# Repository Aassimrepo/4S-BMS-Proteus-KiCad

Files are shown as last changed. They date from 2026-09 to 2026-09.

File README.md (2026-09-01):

# 4S Battery Management System (BMS)

### Proteus Simulation & KiCad PCB Design

A simulation-based **4S Battery Management System (BMS)** designed to monitor individual battery cells, estimate pack state, detect abnormal operating conditions, and control passive cell balancing.

The project combines **Arduino-based embedded control, Proteus circuit simulation, and KiCad PCB design** to develop and validate the BMS architecture before physical hardware fabrication.

---

## Overview

A Battery Management System is responsible for monitoring and protecting rechargeable battery packs during charging and discharging.

This project implements a **4-series-cell (4S) BMS**, where each individual cell is monitored independently. The system measures cell voltage, pack voltage, current, and temperature while providing protection and balancing functionality.

The complete design was developed and tested in simulation using **Proteus**, while the corresponding PCB was designed and routed using **KiCad**.

> **Note:** This is a simulation and PCB-design project. No physical battery hardware is used in the current implementation.

---

## Key Features

* Individual voltage monitoring for all **4 battery cells**
* Total battery pack voltage calculation
* Battery **State of Charge (SOC)** estimation
* Overvoltage protection
* Undervoltage protection
* Overcurrent detection
* Overtemperature detection
* Passive cell-balancing control
* Individual cell-balancing indicators
* Charge and load status indication
* Fault indication
* ACS712-based current sensing model
* NTC thermistor temperature sensing
* Nokia 5110 LCD monitoring
* Arduino-based embedded control
* Serial telemetry between controllers
* Complete KiCad schematic and PCB layout
* PCB routing and Design Rules Check (**DRC**)

---

## System Architecture

```text
                     ┌──────────────────────┐
                     │      4S Battery      │
                     │   Cell 1 - Cell 4   │
                     └──────────┬───────────┘
                                │
                                ▼
                     ┌──────────────────────┐
                     │   Voltage Divider    │
                     │   Sensing Network    │
                     └──────────┬───────────┘
                                │
                                ▼
                 ┌──────────────────────────────┐
                 │      Arduino BMS Controller  │
                 │                              │
                 │ • Cell Voltage Monitoring    │
                 │ • Pack Voltage Calculation   │
                 │ • SOC Estimation             │
                 │ • Fault Detection            │
                 │ • Balancing Control          │
                 └───────┬──────────┬───────────┘
                         │          │
              ┌──────────┘          └───────────┐
              ▼                                 ▼
      ┌───────────────┐                 ┌───────────────┐
      │  Nokia 5110   │                 │ Status / Fault│
      │     LCD       │                 │     LEDs      │
      └───────────────┘                 └───────────────┘
                         │
                         ▼
                 ┌─────────────────┐
                 │ Secondary MCU / │
                 │ Telemetry Link  │
                 └─────────────────┘
```

---

## Cell Voltage Measurement

The four battery-cell inputs are measured using resistor-divider networks connected to the Arduino's analog inputs.

The divider networks allow the cumulative battery tap voltages to be scaled into a measurable ADC range.

| Cell | Divider Network | Software Scaling |
| --- | --- | ---: |
| Cell 1 | 10k / 10k | ×2 |
| Cell 2 | 20k / 10k | ×3 |
| Cell 3 | 30k / 10k | ×4 |
| Cell 4 | 40k / 10k | ×5 |

The controller converts the measured ADC values into cell-voltage estimates and calculates the pack voltage from the four cell measurements.

---

## Battery Monitoring

The system continuously monitors:

* Cell 1 voltage
* Cell 2 voltage
* Cell 3 voltage
* Cell 4 voltage
* Pack voltage
* State of Charge (SOC)
* Battery current
* Battery temperature

ADC averaging and software filtering are used to reduce measurement fluctuations and reject invalid readings during simulation.

---

## Protection System

The BMS evaluates the measured parameters against configurable safety thresholds.

### Overvoltage

Each cell voltage is independently checked against the configured overvoltage threshold.

### Undervoltage

Each cell is monitored for voltage falling below the configured undervoltage threshold.

### Overcurrent

The ACS712 sensor model provides the current measurement. The calculated current is compared with the configured current limit.

### Overtemperature

An NTC thermistor model is used to estimate battery temperature. The system generates an overtemperature condition when the configured temperature threshold is exceeded.

### Fault Indication

When a protection condition is detected, the BMS updates its fault state and controls the corresponding protection/status outputs.

---

## Passive Cell Balancing

The BMS implements simulated passive balancing for each individual cell.

```text
Cell 1 ──► BAL1
Cell 2 ──► BAL2
Cell 3 ──► BAL3
Cell 4 ──► BAL4
```

Each balancing channel can be activated independently depending on the measured cell voltage.

The balancing state is also encoded into a telemetry value for communication to the secondary controller.

---

## LCD Interface

A **Nokia 5110 LCD** provides local monitoring of the simulated battery system.

The display provides multiple monitoring pages containing:

### Cell Monitoring

* Cell 1 voltage
* Cell 2 voltage
* Cell 3 voltage
* Cell 4 voltage
* Pack voltage
* SOC

### Current & Temperature

* Battery current
* Battery temperature

### Pack Summary

* Pack voltage
* SOC
* Telemetry status

---

## Controller Communication

The primary controller periodically transmits monitoring information to the secondary controller through serial communication.

The telemetry packet contains:

```text
Cell 1
Cell 2
Cell 3
Cell 4
Pack Voltage
SOC
Current
Temperature
Fault Code
Balancing Code
```

### Fault Codes

| Code | Condition |
| ---: | --- |
| 0 | No Fault |
| 1 | Overvoltage |
| 2 | Undervoltage |
| 3 | Overcurrent |
| 4 | Overtemperature |

The balancing status is represented using a bit-coded value, allowing the state of the four balancing channels to be transmitted efficiently.

---

## Proteus Simulation

The complete BMS control system is simulated in **Proteus**.

The simulation models:

* Battery-cell voltage inputs
* Voltage-divider sensing circuits
* Arduino controllers
* ACS712 current sensor
* NTC thermistor
* Nokia 5110 LCD
* Status LEDs
* Cell-balancing outputs
* Serial communication

Different operating conditions can be introduced by changing the simulated sensor and battery inputs.

This allows the BMS control logic to be evaluated without physical battery hardware.

---

## PCB Design

The corresponding BMS PCB was designed using **KiCad**.

The PCB design includes the circuitry required for:

* Battery connections
* Cell-voltage sensing
* Current sensing
* Temperature sensing
* Microcontroller interfaces
* Cell balancing
* Status indicators
* Buzzer
* Display interface
* Communication interfaces
* ESP8266 interface

The PCB was routed and subsequently checked using KiCad's Design Rules Checker.

---

## PCB Validation

The completed PCB layout was subjected to KiCad's **Design Rules Check (DRC)**.

### Final DRC Result

```text
0 Violations
```

This confirms that the final PCB layout passed the configured KiCad design-rule checks.

---

## Repository Structure

```text
4S-BMS-Proteus-KiCad/
│
├── Proteus/
│   ├── Simulation/
│   │   ├── *.dsn
│   │   └── *.pdsprj
│   │
│   ├── Arduino_Code/
│   │   ├── *.ino
│   │   └── ...
│   │
│   └── HEX_Files/
│       └── *.hex
│
├── KiCad_PCB/
│   ├── Source/
│   │   ├── *.kicad_pro
│   │   ├── *.kicad_sch
│   │   └── *.kicad_pcb
│   │
│   └── Outputs/
│       ├── PCB_3D_Render.png
│       └── PCB_Layout.png
│
├── Documentation/
│   ├── Screenshots/
│   └── Results/
│
├── .gitignore
└── README.md
```

---

## Testing

The simulated BMS can be evaluated under different operating conditions.

| Test Condition | Input | Expected Behaviour |
| --- | --- | --- |
| Normal Operation | Normal cell voltages | Normal monitoring |
| Overvoltage | Cell exceeds OV limit | Fault/protection indication |
| Undervoltage | Cell falls below UV limit | Load protection/fault |
| Overcurrent | Current exceeds limit | Overcurrent protection |
| Overtemperature  | Temperature exceeds limit | Temperature protection |
| Cell Balancing | Cell reaches balancing threshold | Corresponding balancing output |
| Recovery | Fault condition removed | Return to normal operation |

Screenshots demonstrating the simulation and PCB validation are available in the `Documentation/Screenshots` directory.

---

## Technologies Used

### Hardware / Controllers

* Arduino Uno
* Arduino Nano
* ESP8266 interface
* ACS712 current sensor
* NTC thermistor
* Nokia 5110 LCD
* Passive balancing circuitry

### Software

* Proteus
* KiCad
* Arduino IDE
* C/C++

---

## Future Development

The project can be extended into an IoT-enabled battery monitoring platform.

Planned extensions include:

* Raspberry Pi 5 IoT gateway
* Real-time web dashboard
* Remote BMS telemetry
* Live voltage/current/temperature graphs
* Historical data logging
* Battery-state prediction
* Machine-learning based battery analysis
* Remote fault notifications
* Physical hardware implementation and validation

These features are intended as future extensions and are **not represented as completed functionality in the current version of the repository**.

---

## Project Documentation

The repository contains screenshots showing:

* Complete Proteus simulation
* Normal BMS operation
* Fault detection
* PCB routing
* PCB 3D visualization
* KiCad DRC results

Refer to:

```text
Documentation/Screenshots/
```

for the available visual documentation.

---

## Disclaimer

This project is intended for **educational and research purposes**.

The current implementation is a simulation and PCB-design study and has not been validated on physical battery hardware.

A real battery-management system requires appropriate component selection, isolation, protection circuitry, thermal considerations, battery characterization, hardware validation, and extensive safety testing before being used with a real battery pack.

---

## Author

**Aassim Basheer**

Electronics and Communication Engineering

---

## License

This project is provided for educational and research purposes.

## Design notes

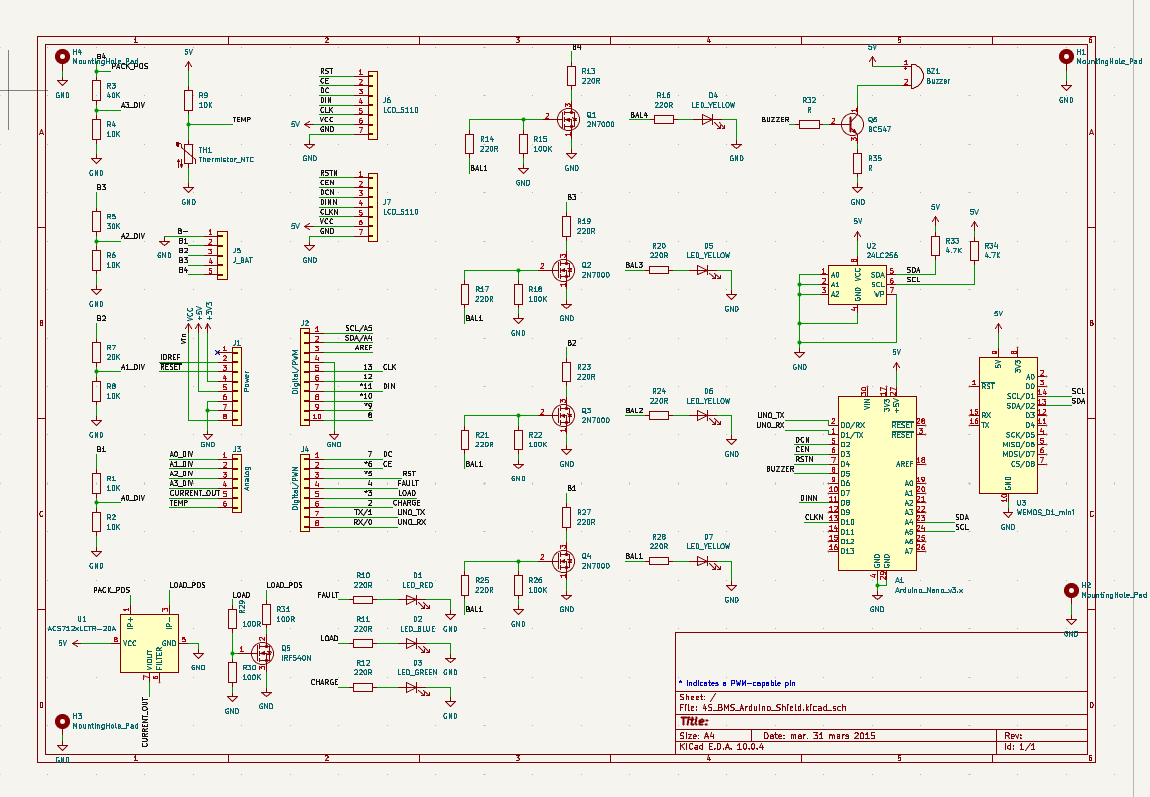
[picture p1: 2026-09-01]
Documentation/Screenshots/PCB SCHEMATIC.png

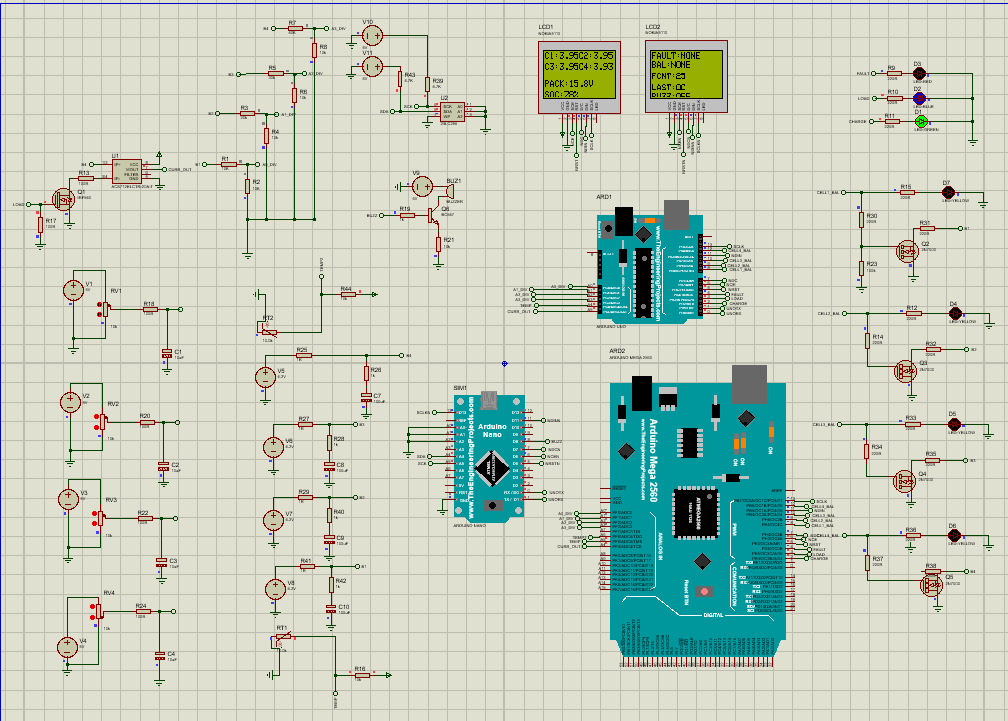
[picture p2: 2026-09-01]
Documentation/Screenshots/PROTEUS SIMULATION.png

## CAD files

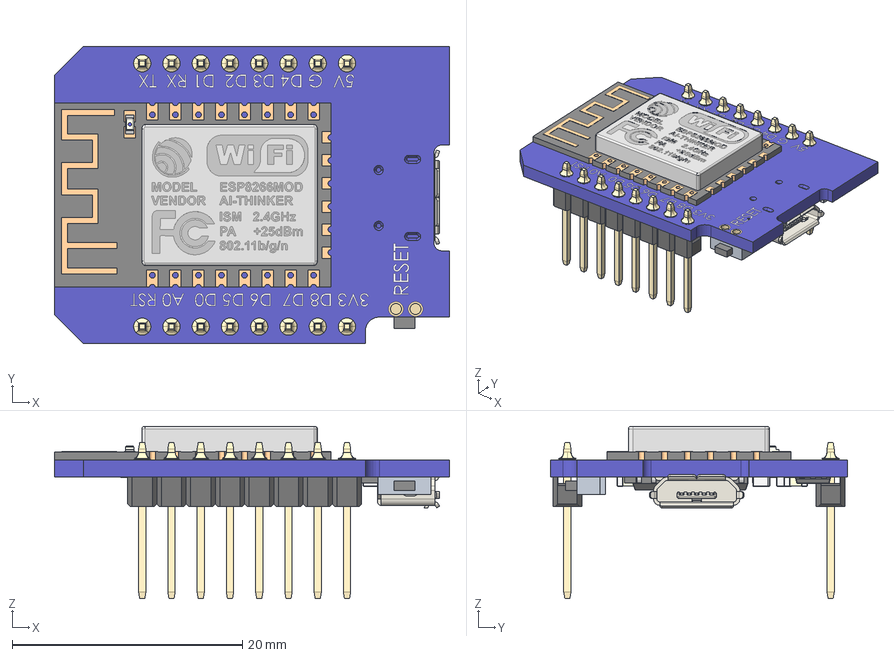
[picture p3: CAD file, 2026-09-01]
KiCad_PCB/Source/kicad bms/wemos-mini-d1.stp
34.3 x 25.8 x 14.9 mm
PRODUCT_146_ASM_2
PRODUCT_260_3
PRODUCT_323_ASM_2
RES_0805_1 x 12
CAP_0805_1 x 7
SOT23_1_1 x 2
SOT23_2_1 x 2
SOT23_3_1 x 2
SOT23_001_1 x 2
SOT23-5_1
SOT23-5_001_1_1
SOT23-5_001_2_1
SOT23-5_001_3_1
SOT23-5_001_4_1
SOT23-5_001_5_1
SOD-323_1
SOIC-16_150MIL_1
SOIC-16_150MIL_001_1_1
SOIC-16_150MIL_001_2_1
SOIC-16_150MIL_001_3_1
SOIC-16_150MIL_001_4_1
SOIC-16_150MIL_001_5_1
SOIC-16_150MIL_001_6_1
SOIC-16_150MIL_001_7_1
SOIC-16_150MIL_001_8_1
SOIC-16_150MIL_001_9_1
SOIC-16_150MIL_001_10_1
SOIC-16_150MIL_001_11_1
SOIC-16_150MIL_001_12_1
SOIC-16_150MIL_001_13_1
SOIC-16_150MIL_001_14_1
SOIC-16_150MIL_001_15_1
SOIC-16_150MIL_001_16_1
COMPONENTS_2_11__2
_PUSH_BUTTON_-_IMPORTIERT1__2
_USB_SOCKET_-_IMPORTIERT1__2
PCB_2
PIN x 16

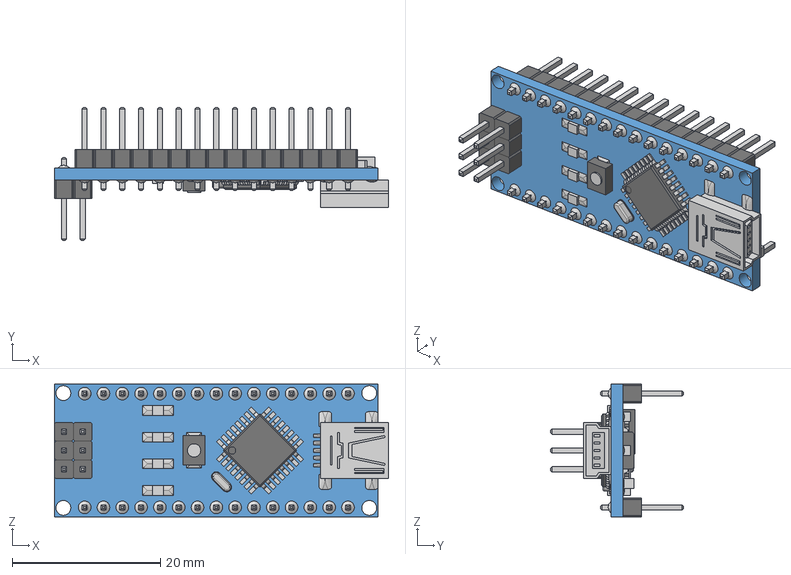
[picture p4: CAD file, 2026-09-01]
KiCad_PCB/Source/kicad bms/Arduino Nano V3.step
45.1 x 18.0 x 17.9 mm
switch
Led x 3
Led (1)
Pin x 21
chip1
USB
Crystal
Pin (1) x 15
Res x 5
cap x 2
Chip
respack x 2
diode
vreg

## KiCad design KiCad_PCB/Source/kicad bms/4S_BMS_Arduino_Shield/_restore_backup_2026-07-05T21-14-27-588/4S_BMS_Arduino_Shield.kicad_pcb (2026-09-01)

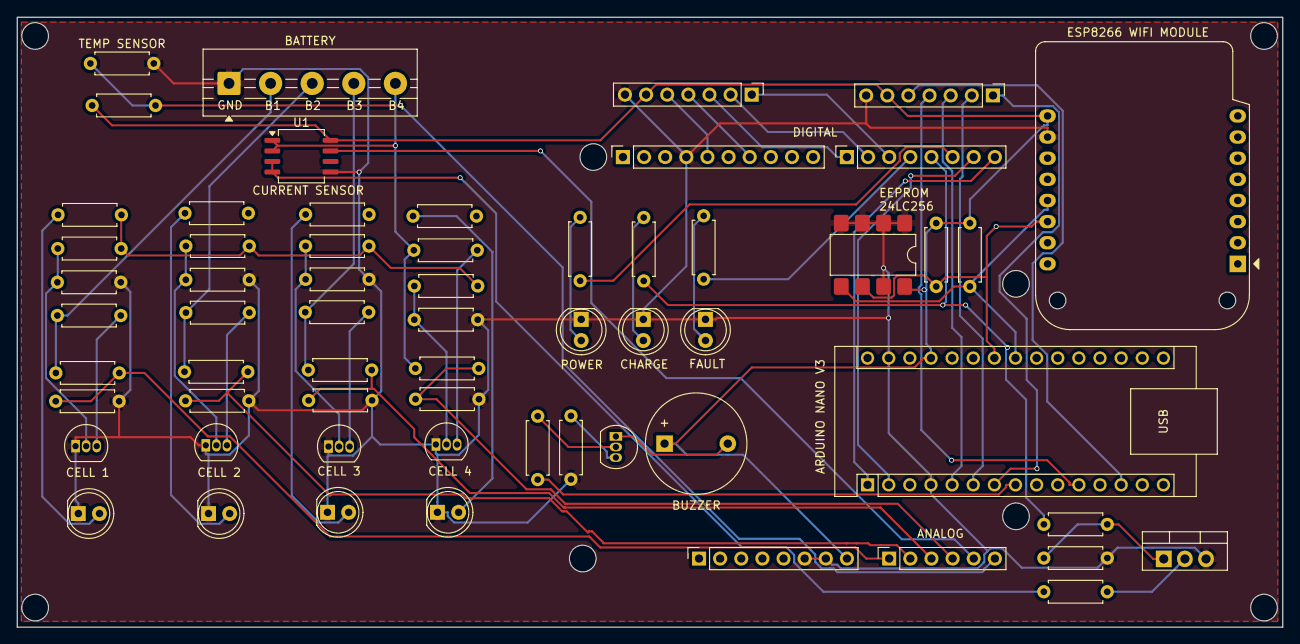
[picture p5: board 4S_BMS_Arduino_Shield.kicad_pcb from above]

Board: 2 copper layers, 152.1 x 73.3 mm, 69 parts (0 on the bottom side), 52 nets.

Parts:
A1: ARDUINO_NANO; Arduino_Nano
BATTERY: J_BAT; TerminalBlock_MaiXu_MX126-5.0-05P_1x05_P5.00mm
BZ1: BUZZER; Buzzer_12x9.5RM7.6
D1: FAULT; LED_D5.0mm
D2: CHARGE; LED_D5.0mm
D3: POWER; LED_D5.0mm
D4: BAL_4; LED_D5.0mm
D5: BAL_3; LED_D5.0mm
D6: BAL_2; LED_D5.0mm
D7: BAL_1; LED_D5.0mm
H1, H2, H3, H4: MountingHole_Pad; MountingHole_3.2mm_M3
J1: Power; PinSocket_1x08_P2.54mm_Vertical
J2: Digital/PWM; PinSocket_1x10_P2.54mm_Vertical
J3: Analog; PinSocket_1x06_P2.54mm_Vertical
J4: Digital/PWM; PinSocket_1x08_P2.54mm_Vertical
J6: LCD_1; PinHeader_1x07_P2.54mm_Vertical
J7: LCD_2; PinHeader_1x07_P2.54mm_Vertical
MH1, MH2, MH3, MH4: MountingHole_3.2mm
Q1, Q2, Q3, Q4: 2N7000; TO-92_Inline
Q5: LOAD; TO-220-3_Vertical
Q6: BC547; TO-92_Inline
R1, R2, R4, R6, R8, R9: 10K; R_Axial_DIN0207_L6.3mm_D2.5mm_P7.62mm_Horizontal
R3: 40K; R_Axial_DIN0207_L6.3mm_D2.5mm_P7.62mm_Horizontal
R5: 30K; R_Axial_DIN0207_L6.3mm_D2.5mm_P7.62mm_Horizontal
R7: 20K; R_Axial_DIN0207_L6.3mm_D2.5mm_P7.62mm_Horizontal
R10, R11, R12, R13, R14, R16, R17, R19, R20, R21, R23, R24, R25, R27, R28: 220R; R_Axial_DIN0207_L6.3mm_D2.5mm_P7.62mm_Horizontal
R15, R18, R22, R26, R30: 100K; R_Axial_DIN0207_L6.3mm_D2.5mm_P7.62mm_Horizontal
R29, R31: 100R; R_Axial_DIN0207_L6.3mm_D2.5mm_P7.62mm_Horizontal
R32, R35: R; R_Axial_DIN0207_L6.3mm_D2.5mm_P7.62mm_Horizontal
R33, R34: 4.7K; R_Axial_DIN0207_L6.3mm_D2.5mm_P7.62mm_Horizontal
TEMP SENSOR: Thermistor_NTC; R_Axial_DIN0207_L6.3mm_D2.5mm_P7.62mm_Horizontal
U1: ACS712xLCTR-20A; SOIC-8_5.3x6.2mm_P1.27mm
U2: EEPROM; SMDIP-8_W7.62mm
U3: ESP8266; WEMOS_C3_mini

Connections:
5V: A1.27 (+5V), BZ1.1 (+), J1.8, J6.6, J7.6, R9.1, R33.1, R34.1, U1.8 (VCC), U2.8 (VCC), U3.9 (5V)
/2: J4.6, R12.2
/4: J4.4, R10.2
/7: J4.1, J6.3
/13: J2.5, J6.5
/*3: J4.5, R11.2, R29.1
/*5: J4.3, J6.1
/*6: J4.2, J6.2
/*11: J2.7, J6.4
/A0_DIV: J3.1, R1.2, R2.1
/A1_DIV: J3.2, R7.2, R8.1
/A2_DIV: J3.3, R5.2, R6.1
/A3_DIV: J3.4, R3.2, R4.1
/B1: BATTERY.2, R1.1, R27.1
/B2: BATTERY.3, R7.1, R23.1
/B3: BATTERY.4, R5.1, R19.1
/B4: BATTERY.5, R3.1, R13.1, U1.1 (IP+), U1.2 (IP+)
/BAL1: R14.2, R17.2, R21.2, R25.2, R28.2
/BUZZER: A1.8 (D5), R32.2
/CEN: A1.6 (D3), J7.2
/CLKN: A1.13 (D10), J7.5
/CURRENT_OUT: J3.5, U1.7 (VIOUT)
/DCN: A1.5 (D2), J7.3
/DINN: A1.11 (D8), J7.4
/LOAD_POS: R31.1, U1.3 (IP-), U1.4 (IP-)
/RSTN: A1.7 (D4), J7.1
/RX/0: A1.1 (D1/TX), J4.8
/SCL: A1.24 (A5), R34.2, U2.6 (SCL), U3.14 (SCL/D1)
/SDA: A1.23 (A4), R33.2, U2.5 (SDA), U3.13 (SDA/D2)
/TEMP: J3.6, R9.2, TEMP SENSOR.1
/TX/1: A1.2 (D0/RX), J4.7
GND: A1.4 (GND), A1.29 (GND), BATTERY.1, D1.1 (K), D2.1 (K), D3.1 (K), D4.1 (K), D5.1 (K), D6.1 (K), D7.1 (K), J1.6, J1.7, J2.4, J6.7, J7.7, Q1.1 (S), Q2.1 (S), Q3.1 (S), Q4.1 (S), Q5.3 (S), R2.2, R4.2, R6.2, R8.2, R15.2, R18.2, R22.2, R26.2, R30.2, R35.2, TEMP SENSOR.2, U1.5 (GND), U2.1 (A0), U2.2 (A1), U2.3 (A2), U2.4 (GND), U2.7 (WP), U3.10 (GND)
unnamed: BZ1.2 (-), Q6.1 (C)
unnamed: D1.2 (A), R10.1
unnamed: D2.2 (A), R11.1
unnamed: D3.2 (A), R12.1
unnamed: D4.2 (A), R16.1
unnamed: D5.2 (A), R20.1
unnamed: D6.2 (A), R24.1
unnamed: D7.2 (A), R28.1
unnamed: Q1.3 (D), R13.2
unnamed: Q1.2 (G), R14.1, R15.1
unnamed: Q2.3 (D), R19.2
unnamed: Q2.2 (G), R17.1, R18.1
unnamed: Q3.3 (D), R23.2
unnamed: Q3.2 (G), R21.1, R22.1
unnamed: Q4.3 (D), R27.2
unnamed: Q4.2 (G), R25.1, R26.1
unnamed: Q5.2 (D), R31.2
unnamed: Q5.1 (G), R29.2, R30.1
unnamed: Q6.2 (B), R32.1
unnamed: Q6.3 (E), R35.1

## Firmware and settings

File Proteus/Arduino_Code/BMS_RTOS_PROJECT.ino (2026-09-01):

/*
 ============================================================
        4S BMS - PROTEUS SIMULATION VERSION
        Arduino UNO MAIN CONTROLLER
 ============================================================

 Designed specifically for the Proteus circuit:

 B1 -> 10k / 10k divider -> A0
 B2 -> 20k / 10k divider -> A1
 B3 -> 30k / 10k divider -> A2
 B4 -> 40k / 10k divider -> A3

 IMPORTANT:
 B1, B2, B3 and B4 are treated as INDIVIDUAL CELL VOLTAGES.

 Example:
 B1 = 4.2V
 B2 = 4.2V
 B3 = 4.2V
 B4 = 4.2V

 Arduino calculates:
 Cell 1 = approximately 4.2V
 Cell 2 = approximately 4.2V
 Cell 3 = approximately 4.2V
 Cell 4 = approximately 4.2V

 Pack = approximately 16.8V

 ============================================================
*/


#include <Adafruit_GFX.h>
#include <Adafruit_PCD8544.h>
#include <math.h>


// ============================================================
// NOKIA 5110 LCD
// CLK, DIN, DC, CE, RST
// ============================================================

Adafruit_PCD8544 display(13, 11, 7, 6, 5);


// ============================================================
// STATUS LED PINS
// ============================================================

#define CHARGE_LED 2
#define LOAD_LED   3
#define FAULT_LED  4


// ============================================================
// CELL BALANCING LED / MOSFET OUTPUTS
// ============================================================

#define BAL1_PIN 8
#define BAL2_PIN 9
#define BAL3_PIN 10
#define BAL4_PIN 12


// ============================================================
// ANALOG INPUTS
// ============================================================

#define CELL1_PIN A0
#define CELL2_PIN A1
#define CELL3_PIN A2
#define CELL4_PIN A3

#define CURRENT_PIN A4
#define TEMP_PIN    A5


// ============================================================
// ADC CONFIGURATION
// ============================================================

const float ADC_REFERENCE = 5.00;
const float ADC_MAX       = 1023.0;


// ============================================================
// VOLTAGE DIVIDER MULTIPLIERS
//
// B1: 10k / 10k  -> x2
// B2: 20k / 10k  -> x3
// B3: 30k / 10k  -> x4
// B4: 40k / 10k  -> x5
// ============================================================

const float CELL1_MULTIPLIER = 2.0;
const float CELL2_MULTIPLIER = 3.0;
const float CELL3_MULTIPLIER = 4.0;
const float CELL4_MULTIPLIER = 5.0;


// ============================================================
// BMS LIMITS
//
// These are deliberately separated.
//
// 4.20V = normal full cell
// 4.25V = start passive balancing
// 4.30V = overvoltage fault
//
// You can temporarily increase OV_LIMIT for testing.
// ============================================================

const float CELL_OV_LIMIT = 4.30;
const float CELL_UV_LIMIT = 2.00;

const float BALANCE_START = 4.25;

const float CURRENT_LIMIT = 2.00;
const float TEMP_LIMIT    = 60.0;


// ============================================================
// CURRENT SENSOR CONFIGURATION
//
// For Proteus simulation the ACS712 zero-current output
// can vary depending on how the model is configured.
//
// We use a configurable zero voltage.
// ============================================================

const float ACS_ZERO_VOLTAGE = 2.50;
const float ACS_SENSITIVITY  = 0.100;


// ============================================================
// THERMISTOR CONFIGURATION
// ============================================================

const float THERMISTOR_NOMINAL = 10000.0;
const float SERIES_RESISTOR    = 10000.0;
const float BETA_VALUE         = 3950.0;
const float NOMINAL_TEMP_K    = 298.15;


// ============================================================
// CELL VOLTAGE VARIABLES
// ============================================================

float cell1 = 0.0;
float cell2 = 0.0;
float cell3 = 0.0;
float cell4 = 0.0;

float packVoltage = 0.0;


// ============================================================
// OTHER SENSOR VARIABLES
// ============================================================

float currentA = 0.0;
float tempC    = 25.0;
float soc      = 0.0;


// ============================================================
// RAW ADC VOLTAGES
//
// Useful for debugging Proteus.
// ============================================================

float rawA0 = 0.0;
float rawA1 = 0.0;
float rawA2 = 0.0;
float rawA3 = 0.0;


// ============================================================
// FAULT FLAGS
// ============================================================

bool overVoltage  = false;
bool underVoltage = false;
bool overCurrent  = false;
bool overTemp     = false;
bool fault        = false;


// ============================================================
// INDIVIDUAL CELL FAULT FLAGS
// ============================================================

bool ov1 = false;
bool ov2 = false;
bool ov3 = false;
bool ov4 = false;

bool uv1 = false;
bool uv2 = false;
bool uv3 = false;
bool uv4 = false;


// ============================================================
// BALANCING FLAGS
// ============================================================

bool bal1 = false;
bool bal2 = false;
bool bal3 = false;
bool bal4 = false;


// ============================================================
// CODES SENT TO NANO
//
// faultCode:
// 0 = Normal
// 1 = Overvoltage
// 2 = Undervoltage
// 3 = Overcurrent
// 4 = Overtemperature
//
// balCode:
// bit 0 = Cell 1
// bit 1 = Cell 2
// bit 2 = Cell 3
// bit 3 = Cell 4
// ============================================================

byte faultCode = 0;
byte balCode   = 0;


// ============================================================
// LCD
// ============================================================

int page = 0;

unsigned long lastPageChange = 0;
unsigned long lastTelemetry  = 0;
unsigned long lastDebug      = 0;


// ============================================================
// READ ADC VOLTAGE
// ============================================================

float readADCVoltage(int pin)
{
    long total = 0;

    const int samples = 20;

    for (int i = 0; i < samples; i++)
    {
        total += analogRead(pin);
        delayMicroseconds(200);
    }

    float averageADC = total / (float)samples;

    return averageADC * ADC_REFERENCE / ADC_MAX;
}


// ============================================================
// READ CELL VOLTAGE
//
// No aggressive filtering here.
//
// This is intentional.
//
// Your previous filtering could make Proteus testing
// confusing because the displayed value could lag behind
// the actual source voltage.
//
// A small exponential filter is still used to stabilize
// the display.
// ============================================================

float filterVoltage(float previous, float measured)
{
    const float FILTER_ALPHA = 0.35;

    if (previous <= 0.1)
        return measured;

    return previous * (1.0 - FILTER_ALPHA)
           + measured * FILTER_ALPHA;
}


// ============================================================
// READ ALL FOUR CELLS
// ============================================================

void readCells()
{
    // Read actual ADC-side voltages

    rawA0 = readADCVoltage(CELL1_PIN);
    rawA1 = readADCVoltage(CELL2_PIN);
    rawA2 = readADCVoltage(CELL3_PIN);
    rawA3 = readADCVoltage(CELL4_PIN);


    // Convert divider voltage back to cell voltage

    float measuredCell1 = rawA0 * CELL1_MULTIPLIER;
    float measuredCell2 = rawA1 * CELL2_MULTIPLIER;
    float measuredCell3 = rawA2 * CELL3_MULTIPLIER;
    float measuredCell4 = rawA3 * CELL4_MULTIPLIER;


    // Sanity limits
    //
    // These prevent impossible readings caused by
    // floating inputs or ADC noise.

    if (measuredCell1 < 0.0 || measuredCell1 > 10.5)
        measuredCell1 = cell1;

    if (measuredCell2 < 0.0 || measuredCell2 > 10.5)
        measuredCell2 = cell2;

    if (measuredCell3 < 0.0 || measuredCell3 > 10.5)
        measuredCell3 = cell3;

    if (measuredCell4 < 0.0 || measuredCell4 > 10.5)
        measuredCell4 = cell4;


    // Filter

    cell1 = filterVoltage(cell1, measuredCell1);
    cell2 = filterVoltage(cell2, measuredCell2);
    cell3 = filterVoltage(cell3, measuredCell3);
    cell4 = filterVoltage(cell4, measuredCell4);


    // Calculate pack

    packVoltage =
        cell1 +
        cell2 +
        cell3 +
        cell4;
}


// ============================================================
// CALCULATE SOC
//
// 4S Li-ion approximation:
//
// 12.0V = 0%
// 16.8V = 100%
//
// This is a simple simulation SOC model,
// NOT a real battery fuel-gauge algorithm.
// ============================================================

void updateSOC()
{
    soc = ((packVoltage - 12.0) / 4.8) * 100.0;


    if (soc < 0.0)
        soc = 0.0;

    if (soc > 100.0)
        soc = 100.0;
}


// ============================================================
// READ ACS712 CURRENT
// ============================================================

float readCurrent()
{
    float sensorVoltage = readADCVoltage(CURRENT_PIN);

    float current =
        (sensorVoltage - ACS_ZERO_VOLTAGE)
        / ACS_SENSITIVITY;


    // Absolute value for simple Proteus simulation

    if (current < 0)
        current = -current;


    // Remove small simulated noise

    if (current < 0.10)
        current = 0.0;


    return current;
}


// ============================================================
// READ THERMISTOR
// ============================================================

float readTemperature()
{
    int adc = analogRead(TEMP_PIN);


    // If input is essentially disconnected,
    // return room temperature for simulation.

    if (adc <= 2 || adc >= 1021)
        return 25.0;


    float resistance =
        SERIES_RESISTOR *
        ((ADC_MAX / (float)adc) - 1.0);


    if (resistance <= 0)
        return 25.0;


    float temperatureK =
        1.0 /
        (
            (log(resistance / THERMISTOR_NOMINAL)
             / BETA_VALUE)
            +
            (1.0 / NOMINAL_TEMP_K)
        );


    float temperatureC =
        temperatureK - 273.15;


    // Reject completely unrealistic values

    if (temperatureC < -40.0 ||
        temperatureC > 150.0)
    {
        return 25.0;
    }


    return temperatureC;
}


// ============================================================
// FAULT DETECTION
// ============================================================

void updateFaults()
{
    // Individual overvoltage

    ov1 = cell1 > CELL_OV_LIMIT;
    ov2 = cell2 > CELL_OV_LIMIT;
    ov3 = cell3 > CELL_OV_LIMIT;
    ov4 = cell4 > CELL_OV_LIMIT;


    // Individual undervoltage

    uv1 = cell1 < CELL_UV_LIMIT;
    uv2 = cell2 < CELL_UV_LIMIT;
    uv3 = cell3 < CELL_UV_LIMIT;
    uv4 = cell4 < CELL_UV_LIMIT;


    // Combined conditions

    overVoltage =
        ov1 ||
        ov2 ||
        ov3 ||
        ov4;


    underVoltage =
        uv1 ||
        uv2 ||
        uv3 ||
        uv4;


    overCurrent =
        currentA > CURRENT_LIMIT;


    overTemp =
        tempC > TEMP_LIMIT;


    // Overall fault

    fault =
        overVoltage ||
        underVoltage ||
        overCurrent ||
        overTemp;


    // Priority system

    if (overVoltage)
    {
        faultCode = 1;
    }
    else if (underVoltage)
    {
        faultCode = 2;
    }
    else if (overCurrent)
    {
        faultCode = 3;
    }
    else if (overTemp)
    {
        faultCode = 4;
    }
    else
    {
        faultCode = 0;
    }
}


// ============================================================
// PASSIVE BALANCING
//
// IMPORTANT:
//
// Balancing is NOT the same thing as overvoltage protection.
//
// A cell can be at 4.25V and start balancing,
// while the actual overvoltage fault is 4.30V.
//
// This prevents your yellow balancing LEDs from being
// directly tied to the OV fault condition.
// ============================================================

void updateBalancing()
{
    bal1 = cell1 >= BALANCE_START;
    bal2 = cell2 >= BALANCE_START;
    bal3 = cell3 >= BALANCE_START;
    bal4 = cell4 >= BALANCE_START;


    digitalWrite(
        BAL1_PIN,
        bal1 ? HIGH : LOW
    );


    digitalWrite(
        BAL2_PIN,
        bal2 ? HIGH : LOW
    );


    digitalWrite(
        BAL3_PIN,
        bal3 ? HIGH : LOW
    );


    digitalWrite(
        BAL4_PIN,
        bal4 ? HIGH : LOW
    );


    // Generate balancing bit code

    balCode = 0;


    if (bal1)
        balCode |= 1;


    if (bal2)
        balCode |= 2;


    if (bal3)
        balCode |= 4;


    if (bal4)
        balCode |= 8;
}


// ============================================================
// STATUS LED CONTROL
// ============================================================

void updateOutputs()
{
    // CHARGE
    //
    // Charging is disabled for:
    // OV
    // OT

    if (overVoltage || overTemp)
        digitalWrite(CHARGE_LED, LOW);
    else
        digitalWrite(CHARGE_LED, HIGH);


    // LOAD
    //
    // Load disabled for:
    // UV
    // OC
    // OT

    if (underVoltage ||
        overCurrent ||
        overTemp)
    {
        digitalWrite(LOAD_LED, LOW);
    }
    else
    {
        digitalWrite(LOAD_LED, HIGH);
    }


    // Fault LED

    if (fault)
        digitalWrite(FAULT_LED, HIGH);
    else
        digitalWrite(FAULT_LED, LOW);
}


// ============================================================
// SEND TELEMETRY TO NANO
//
// Format:
//
// cell1,
// cell2,
// cell3,
// cell4,
// packVoltage,
// SOC,
// current,
// temperature,
// faultCode,
// balancingCode
// ============================================================

void sendTelemetryToNano()
{
    Serial.print(cell1, 2);
    Serial.print(",");

    Serial.print(cell2, 2);
    Serial.print(",");

    Serial.print(cell3, 2);
    Serial.print(",");

    Serial.print(cell4, 2);
    Serial.print(",");

    Serial.print(packVoltage, 2);
    Serial.print(",");

    Serial.print((int)soc);
    Serial.print(",");

    Serial.print(currentA, 2);
    Serial.print(",");

    Serial.print(tempC, 1);
    Serial.print(",");

    Serial.print(faultCode);
    Serial.print(",");

    Serial.println(balCode);
}


// ============================================================
// SERIAL DEBUG
//
// This is extremely important for Proteus.
//
// It lets us see:
//
// ADC A0-A3
// calculated cell voltages
// pack voltage
// current
// temperature
// fault
// balancing
// ============================================================

void sendDebugData()
{
    Serial.println();
    Serial.println("========== BMS DEBUG ==========");


    Serial.print("ADC A0 = ");
    Serial.print(rawA0, 3);
    Serial.println(" V");


    Serial.print("ADC A1 = ");
    Serial.print(rawA1, 3);
    Serial.println(" V");


    Serial.print("ADC A2 = ");
    Serial.print(rawA2, 3);
    Serial.println(" V");


    Serial.print("ADC A3 = ");
    Serial.print(rawA3, 3);
    Serial.println(" V");


    Serial.println();


    Serial.print("CELL 1 = ");
    Serial.print(cell1, 2);
    Serial.println(" V");


    Serial.print("CELL 2 = ");
    Serial.print(cell2, 2);
    Serial.println(" V");


    Serial.print("CELL 3 = ");
    Serial.print(cell3, 2);
    Serial.println(" V");


    Serial.print("CELL 4 = ");
    Serial.print(cell4, 2);
    Serial.println(" V");


    Serial.print("PACK = ");
    Serial.print(packVoltage, 2);
    Serial.println(" V");


    Serial.print("SOC = ");
    Serial.print(soc, 1);
    Serial.println(" %");


    Serial.print("CURRENT = ");
    Serial.print(currentA, 2);
    Serial.println(" A");


    Serial.print("TEMP = ");
    Serial.print(tempC, 1);
    Serial.println(" C");


    Serial.println();


    Serial.print("OV = ");
    Serial.println(overVoltage ? "YES" : "NO");


    Serial.print("UV = ");
    Serial.println(underVoltage ? "YES" : "NO");


    Serial.print("OC = ");
    Serial.println(overCurrent ? "YES" : "NO");


    Serial.print("OT = ");
    Serial.println(overTemp ? "YES" : "NO");


    Serial.print("FAULT CODE = ");
    Serial.println(faultCode);


    Serial.print("BALANCING CODE = ");
    Serial.println(balCode);


    Serial.println("===============================");
}


// ============================================================
// LCD PAGE 0
// CELL VOLTAGES
// ============================================================

void displayCellPage()
{
    display.setCursor(0, 0);

    display.print("C1:");
    display.print(cell1, 2);


    display.setCursor(42, 0);

    display.print("C2:");
    display.print(cell2, 2);


    display.setCursor(0, 12);

    display.print("C3:");
    display.print(cell3, 2);


    display.setCursor(42, 12);

    display.print("C4:");
    display.print(cell4, 2);


    display.setCursor(0, 28);

    display.print("PACK:");
    display.print(packVoltage, 1);
    display.print("V");


    display.setCursor(0, 42);

    display.print("SOC:");
    display.print((int)soc);
    display.print("%");
}


// ============================================================
// LCD PAGE 1
// CURRENT + TEMPERATURE
// ============================================================

void displaySensorPage()
{
    display.setCursor(0, 0);

    display.print("CURRENT");


    display.setCursor(0, 12);

    display.print(currentA, 2);
    display.print(" A");


    display.setCursor(0, 28);

    display.print("TEMP");


    display.setCursor(0, 40);

    display.print(tempC, 1);
    display.print(" C");
}


// ============================================================
// LCD PAGE 2
// BMS STATUS
// ============================================================

void displayStatusPage()
{
    display.setCursor(0, 0);

    display.print("BMS STATUS");


    display.setCursor(0, 14);

    if (fault)
    {
        display.print("FAULT:");
        display.print(faultCode);
    }
    else
    {
        display.print("NORMAL");
    }


    display.setCursor(0, 28);

    display.print("BAL:");

    if (bal1)
        display.print("1 ");

    if (bal2)
        display.print("2 ");

    if (bal3)
        display.print("3 ");

    if (bal4)
        display.print("4 ");

    if (!bal1 &&
        !bal2 &&
        !bal3 &&
        !bal4)
    {
        display.print("NONE");
    }


    display.setCursor(0, 42);

    display.print("TX -> NANO");
}


// ============================================================
// UPDATE LCD
// ============================================================

void updateLCD()
{
    // Automatically change page every 3 seconds

    if (millis() - lastPageChange >= 3000)
    {
        page++;

        if (page > 2)
            page = 0;

        lastPageChange = millis();
    }


    display.clearDisplay();


    if (page == 0)
    {
        displayCellPage();
    }
    else if (page == 1)
    {
        displaySensorPage();
    }
    else
    {
        displayStatusPage();
    }


    display.display();
}


// ============================================================
// SETUP
// ============================================================
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
void loop()
{
    // --------------------------------------------------------
    // 1. Read cell voltages
    // --------------------------------------------------------

    readCells();


    // --------------------------------------------------------
    // 2. Read current
    // --------------------------------------------------------

    currentA = readCurrent();


    // --------------------------------------------------------
    // 3. Read temperature
    // --------------------------------------------------------

    tempC = readTemperature();


    // --------------------------------------------------------
    // 4. Calculate SOC
    // --------------------------------------------------------

    updateSOC();


    // --------------------------------------------------------
    // 5. Detect faults
    // --------------------------------------------------------

    updateFaults();


    // --------------------------------------------------------
    // 6. Control balancing
    // --------------------------------------------------------

    updateBalancing();


    // --------------------------------------------------------
    // 7. Control status LEDs
    // --------------------------------------------------------

    updateOutputs();


    // --------------------------------------------------------
    // 8. Send telemetry every second
    // --------------------------------------------------------

    if (millis() - lastTelemetry >= 1000)
    {
        sendTelemetryToNano();

        lastTelemetry = millis();
    }


    // --------------------------------------------------------
    // 9. Send detailed debug information every 3 seconds
    // --------------------------------------------------------

    if (millis() - lastDebug >= 3000)
    {
        sendDebugData();

        lastDebug = millis();
    }


    // --------------------------------------------------------
    // 10. Update LCD
    // --------------------------------------------------------

    updateLCD();


    delay(100);
}

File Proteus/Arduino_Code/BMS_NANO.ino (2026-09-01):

/*
NANO AUXILIARY LOGGER / ALARM / IOT GATEWAY
Board: Arduino Nano

Receives BMS telemetry from Uno through RX D0.
Controls buzzer on D8.
Logs faults to 24LC256 EEPROM using A4/A5 I2C.
Reads auxiliary thermistor on A0.
Outputs IoT-ready text through SoftwareSerial D2/D3.

UNO D1/TX -> Nano D0/RX
Common GND required.
*/
#include <Adafruit_GFX.h>
#include <Adafruit_PCD8544.h>

Adafruit_PCD8544 display(13, 11, 7, 6, 5);
#include <Wire.h>
#include <SoftwareSerial.h>
#include <math.h>

SoftwareSerial espSerial(2, 3); // RX, TX

#define BUZZER_PIN 8
#define AUX_TEMP_PIN A0

#define EEPROM_ADDR 0x50

#define ADDR_FAULT_COUNT 0
#define ADDR_LAST_FAULT  10
#define ADDR_LAST_SOC    20
#define ADDR_LAST_TEMP   30
#define ADDR_OV_COUNT    40
#define ADDR_UV_COUNT    50
#define ADDR_OC_COUNT    60
#define ADDR_OT_COUNT    70

float c1 = 0, c2 = 0, c3 = 0, c4 = 0;
float packV = 0;
int soc = 0;
float currentA = 0;
float mainTempC = 25;
float auxTempC = 25;

byte faultCode = 0;
byte balCode = 0;

String rxLine = "";
byte lastLoggedFault = 0;

unsigned long lastLogTime = 0;
unsigned long lastBuzzerToggle = 0;
unsigned long lastIoTPrint = 0;

bool buzzerState = false;

float readAuxTemperature()
{
  int adc = analogRead(AUX_TEMP_PIN);

  if (adc <= 5 || adc >= 1018)
    return 25.0;

  float resistance = 10000.0 * ((1023.0 / adc) - 1.0);

  if (resistance <= 0)
    return 25.0;

  float tempK = 1.0 / (
    (log(resistance / 10000.0) / 3950.0) +
    (1.0 / 298.15)
  );

  float t = tempK - 273.15;

  if (t < -20 || t > 120)
    return 25.0;

  return t;
}

void eepromWriteByte(unsigned int memAddress, byte data)
{
  Wire.beginTransmission(EEPROM_ADDR);
  Wire.write((int)(memAddress >> 8));
  Wire.write((int)(memAddress & 0xFF));
  Wire.write(data);
  Wire.endTransmission();
  delay(5);
}

byte eepromReadByte(unsigned int memAddress)
{
  Wire.beginTransmission(EEPROM_ADDR);
  Wire.write((int)(memAddress >> 8));
  Wire.write((int)(memAddress & 0xFF));
  Wire.endTransmission();

  Wire.requestFrom(EEPROM_ADDR, 1);

  if (Wire.available())
    return Wire.read();

  return 0;
}

void incrementEEPROMCounter(unsigned int addr)
{
  byte value = eepromReadByte(addr);
  value++;
  eepromWriteByte(addr, value);
}

void logFault(byte code)
{
  if (code == 0)
    return;

  incrementEEPROMCounter(ADDR_FAULT_COUNT);
  eepromWriteByte(ADDR_LAST_FAULT, code);
  eepromWriteByte(ADDR_LAST_SOC, (byte)soc);
  eepromWriteByte(ADDR_LAST_TEMP, (byte)mainTempC);

  if (code == 1) incrementEEPROMCounter(ADDR_OV_COUNT);
  else if (code == 2) incrementEEPROMCounter(ADDR_UV_COUNT);
  else if (code == 3) incrementEEPROMCounter(ADDR_OC_COUNT);
  else if (code == 4) incrementEEPROMCounter(ADDR_OT_COUNT);
}

String faultText(byte code)
{
  if (code == 1) return "OV";
  if (code == 2) return "UV";
  if (code == 3) return "OC";
  if (code == 4) return "OT";
  return "NONE";
}

String balanceText(byte code)
{
  String b = "";

  if (code & 1) b += "C1 ";
  if (code & 2) b += "C2 ";
  if (code & 4) b += "C3 ";
  if (code & 8) b += "C4 ";

  if (b.length() == 0)
    b = "NONE";

  return b;
}

void updateBuzzer()
{
  byte activeFault = faultCode;

  if (auxTempC > 60.0 && activeFault == 0)
    activeFault = 4;

  if (activeFault == 0)
  {
    digitalWrite(BUZZER_PIN, LOW);
    buzzerState = false;
    return;
  }

  unsigned long interval = 500;

  if (activeFault == 1) interval = 250;
  else if (activeFault == 2) interval = 700;
  else if (activeFault == 3) interval = 150;
  else if (activeFault == 4) interval = 1000;

  if (millis() - lastBuzzerToggle >= interval)
  {
    buzzerState = !buzzerState;
    digitalWrite(BUZZER_PIN, buzzerState ? HIGH : LOW);
    lastBuzzerToggle = millis();
  }
}

// Parse:
// c1,c2,c3,c4,packV,soc,current,temp,faultCode,balCode
bool parseLine(String line)
{
  line.trim();

  if (line.length() < 10)
    return false;

  float values[8];
  int startIndex = 0;

  for (int i = 0; i < 8; i++)
  {
    int commaIndex = line.indexOf(',', startIndex);
    if (commaIndex == -1)
      return false;

    String token = line.substring(startIndex, commaIndex);
    values[i] = token.toFloat();

    startIndex = commaIndex + 1;
  }

  int commaIndex = line.indexOf(',', startIndex);
  if (commaIndex == -1)
    return false;

  faultCode = (byte)line.substring(startIndex, commaIndex).toInt();
  balCode = (byte)line.substring(commaIndex + 1).toInt();

  c1 = values[0];
  c2 = values[1];
  c3 = values[2];
  c4 = values[3];
  packV = values[4];
  soc = (int)values[5];
  currentA = values[6];
  mainTempC = values[7];

  return true;
}

void readFromUno()
{
  while (Serial.available())
  {
    char ch = Serial.read();

    if (ch == '\n')
    {
      if (parseLine(rxLine))
      {
        if (faultCode != 0)
        {
          if (faultCode != lastLoggedFault || millis() - lastLogTime > 5000)
          {
            logFault(faultCode);
            lastLoggedFault = faultCode;
            lastLogTime = millis();
          }
        }
        else
        {
          lastLoggedFault = 0;
        }
      }

      rxLine = "";
    }
    else
    {
      rxLine += ch;

      if (rxLine.length() > 100)
        rxLine = "";
    }
  }
}

void sendIoTTelemetry()
{
  espSerial.print("C1=");
  espSerial.print(c1, 2);
  espSerial.print(",C2=");
  espSerial.print(c2, 2);
  espSerial.print(",C3=");
  espSerial.print(c3, 2);
  espSerial.print(",C4=");
  espSerial.print(c4, 2);
  espSerial.print(",PACK=");
  espSerial.print(packV, 2);
  espSerial.print(",SOC=");
  espSerial.print(soc);
  espSerial.print(",I=");
  espSerial.print(currentA, 2);
  espSerial.print(",TMAIN=");
  espSerial.print(mainTempC, 1);
  espSerial.print(",TAUX=");
  espSerial.print(auxTempC, 1);
  espSerial.print(",FAULT=");
  espSerial.print(faultText(faultCode));
  espSerial.print(",BAL=");
  espSerial.println(balanceText(balCode));

  espSerial.print("EEPROM_FAULT_COUNT=");
  espSerial.print(eepromReadByte(ADDR_FAULT_COUNT));
  espSerial.print(",LAST_FAULT=");
  espSerial.println(faultText(eepromReadByte(ADDR_LAST_FAULT)));
}

void setup()
{
  Serial.begin(9600);
  espSerial.begin(9600);

  Wire.begin();

  pinMode(BUZZER_PIN, OUTPUT);
  digitalWrite(BUZZER_PIN, LOW);

  espSerial.println("NANO LOGGER READY");
  espSerial.println("Waiting for Uno telemetry...");
  display.begin();
display.setContrast(50);
display.clearDisplay();
display.setCursor(0, 0);
display.println("NANO LOG");
display.println("READY");
display.display();
delay(1000);
}
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
